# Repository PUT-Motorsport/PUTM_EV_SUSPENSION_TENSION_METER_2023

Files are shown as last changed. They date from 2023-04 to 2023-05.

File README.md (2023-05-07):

# Suspension Tension Meter

This circuit is supposed to measure uniaxial forces acting on the push-rods and send collected data over the CAN bus.

<p align="center">
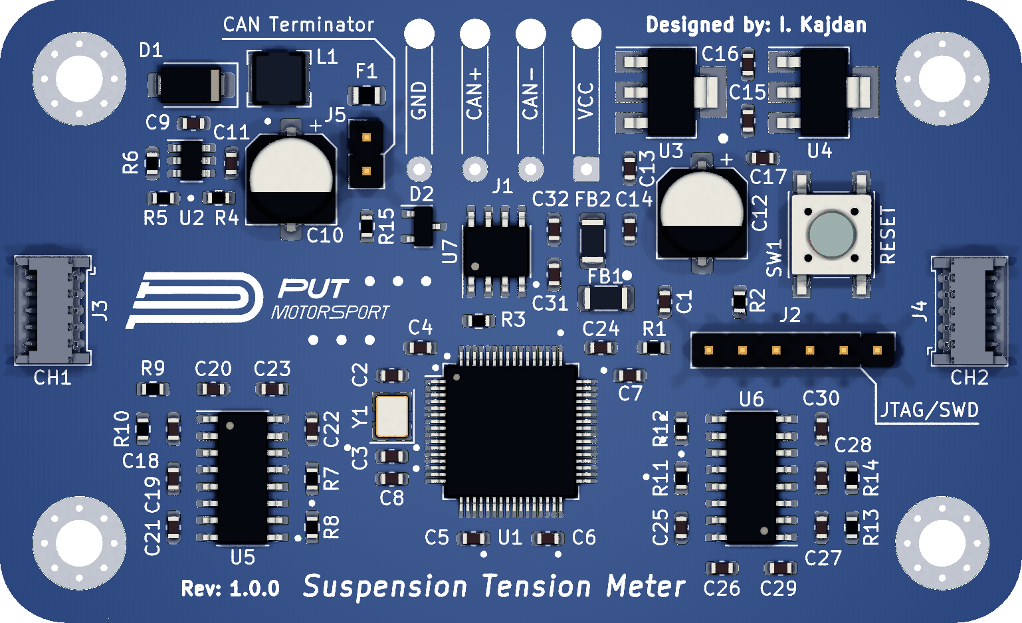
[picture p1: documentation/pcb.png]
  
</p>

## Build

1. Clone the repository:
    ```
    git clone --recurse-submodules 'https://github.com/PUT-Motorsport/PUTM_EV_SUSPENSION_TENSION_METER_2023.git'
    ```
1. Import the project into the CubeIDE.
1. Temporarily rename `main.cpp` to `main.c`.
1. Run the Device Configuration Tool to update the code.
1. Rename `main.c` back to `main.cpp`.

## Firmware

The [Adafruit library](https://github.com/adafruit/Adafruit_NAU7802) and [this project](https://github.com/alex7709/ECE4180F19_CAN_Project) have been used as a reference for writing the driver for the NAU7802.

## Hardware

- [STM32L4P5RET6](https://www.st.com/resource/en/datasheet/stm32l4p5ae.pdf)
- [NAU7802 24-bit ADC](https://www.nuvoton.com/resource-files/NAU7802%20Data%20Sheet%20V1.7.pdf)
- [EMS20 Shear-web Load Cell](https://www.memidos.com/wp-content/uploads/2022/09/EMS20_en.pdf)

## License

    Copyright 2022 Ignacy Kajdan
    
    Licensed under the Apache License, Version 2.0 (the "License");
    you may not use this file except in compliance with the License.
    You may obtain a copy of the License at
    
      https://www.apache.org/licenses/LICENSE-2.0
    
    Unless required by applicable law or agreed to in writing, software
    distributed under the License is distributed on an "AS IS" BASIS,
    WITHOUT WARRANTIES OR CONDITIONS OF ANY KIND, either express or implied.
    See the License for the specific language governing permissions and
    limitations under the License.

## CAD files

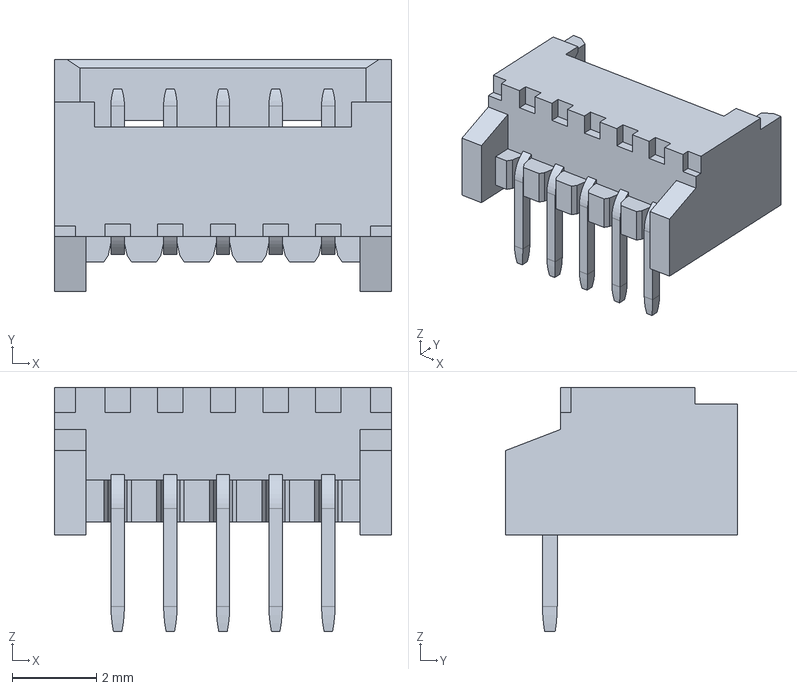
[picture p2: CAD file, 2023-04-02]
hardware/models/Molex_PicoBlade_53048-0510.step
8.00 x 5.50 x 5.80 mm

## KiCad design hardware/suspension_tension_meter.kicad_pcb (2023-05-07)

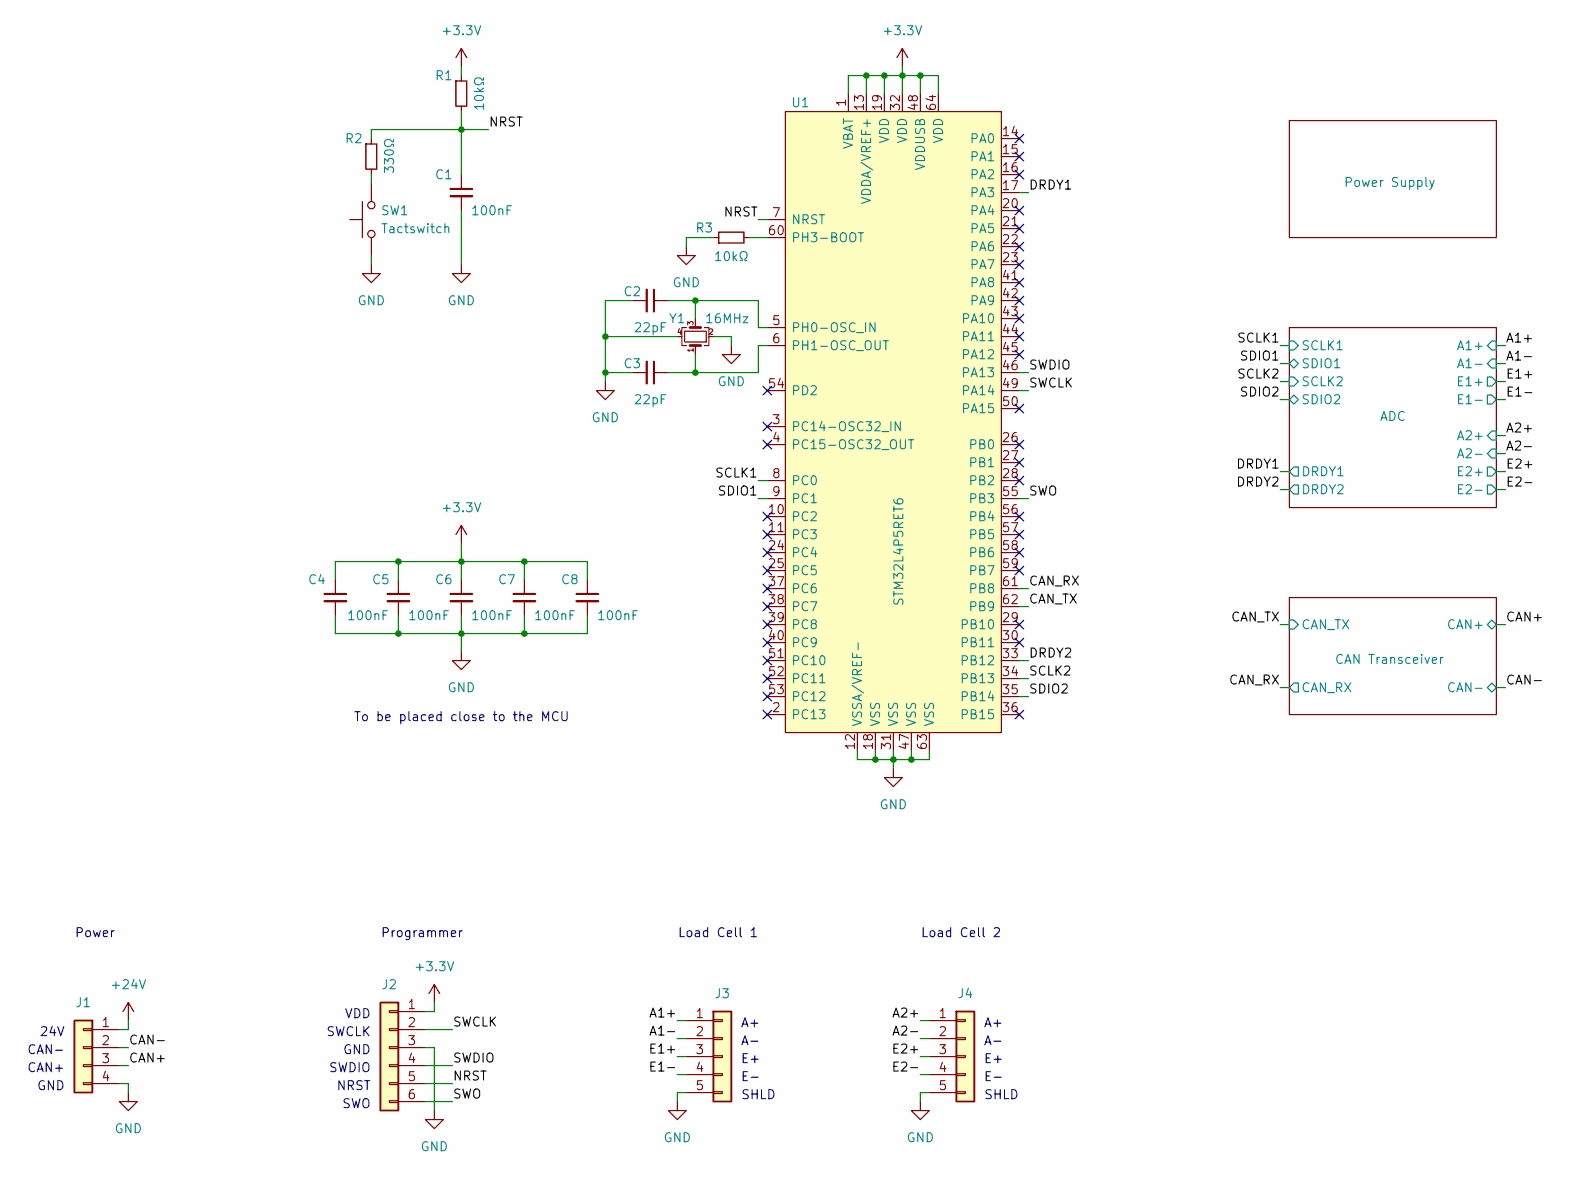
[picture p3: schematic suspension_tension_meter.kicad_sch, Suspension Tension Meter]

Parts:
C1, C4, C5, C6, C7, C8: 100nF; C_0603_1608Metric
C2, C3: 22pF; C_0603_1608Metric
J1: Conn_01x04; SolderWire-0.25sqmm_1x04_P4.2mm_D0.65mm_OD1.7mm_Relief
J2: Conn_01x06; PinHeader_1x06_P2.54mm_Vertical
J3, J4: Conn_01x04; Molex_PicoBlade_53048-0510_1x05_P1.25mm_Horizontal
R1, R3: 10kΩ; R_0603_1608Metric
R2: 330Ω; R_0603_1608Metric
SW1: Tactswitch; SW_SPST_PTS645
U1: STM32L4P5RET6; LQFP-64_10x10mm_P0.5mm
Y1: 16MHz; Crystal_SMD_3225-4Pin_3.2x2.5mm

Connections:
+3.3V: C4.1, C5.1, C6.1, C7.1, C8.1, J2.1, J3.3, J4.3, R1.1, U1.1 (VBAT), U1.13 (VDDA/VREF+), U1.19 (VDD), U1.32 (VDD), U1.48 (VDDUSB), U1.64 (VDD); also elsewhere on the board
+24V: J1.1; also elsewhere on the board
/A1+: J3.1; also elsewhere on the board
/A1-: J3.2; also elsewhere on the board
/A2+: J4.1; also elsewhere on the board
/A2-: J4.2; also elsewhere on the board
/CAN+: J1.3; also elsewhere on the board
/CAN-: J1.2; also elsewhere on the board
/CAN_RX: U1.61 (PB8); also elsewhere on the board
/CAN_TX: U1.62 (PB9); also elsewhere on the board
/DRDY1: U1.17 (PA3); also elsewhere on the board
/DRDY2: U1.33 (PB12); also elsewhere on the board
/NRST: C1.1, J2.5, R1.2, R2.1, U1.7 (NRST)
/SCLK1: U1.8 (PC0); also elsewhere on the board
/SCLK2: U1.34 (PB13); also elsewhere on the board
/SDIO1: U1.9 (PC1); also elsewhere on the board
/SDIO2: U1.35 (PB14); also elsewhere on the board
/SWCLK: J2.2, U1.49 (PA14)
/SWDIO: J2.4, U1.46 (PA13)
/SWO: J2.6, U1.55 (PB3)
GND: C1.2, C2.2, C3.2, C4.2, C5.2, C6.2, C7.2, C8.2, J1.4, J2.3, J3.4, J3.5, J4.4, J4.5, R3.1, SW1.1, U1.12 (VSSA/VREF-), U1.18 (VSS), U1.31 (VSS), U1.47 (VSS), U1.63 (VSS), Y1.2, Y1.4; also elsewhere on the board
unnamed: R2.2, SW1.2
unnamed: C2.1, U1.5 (PH0-OSC_IN), Y1.3
unnamed: C3.1, U1.6 (PH1-OSC_OUT), Y1.1
unnamed: R3.2, U1.60 (PH3-BOOT)

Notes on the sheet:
GND
Power
SHLD
To be placed close to the MCU
Load Cell 2
SWCLK
CAN+
NRST
SWO
SHLD
Load Cell 1
CAN-
VDD
Programmer
SWDIO
24V

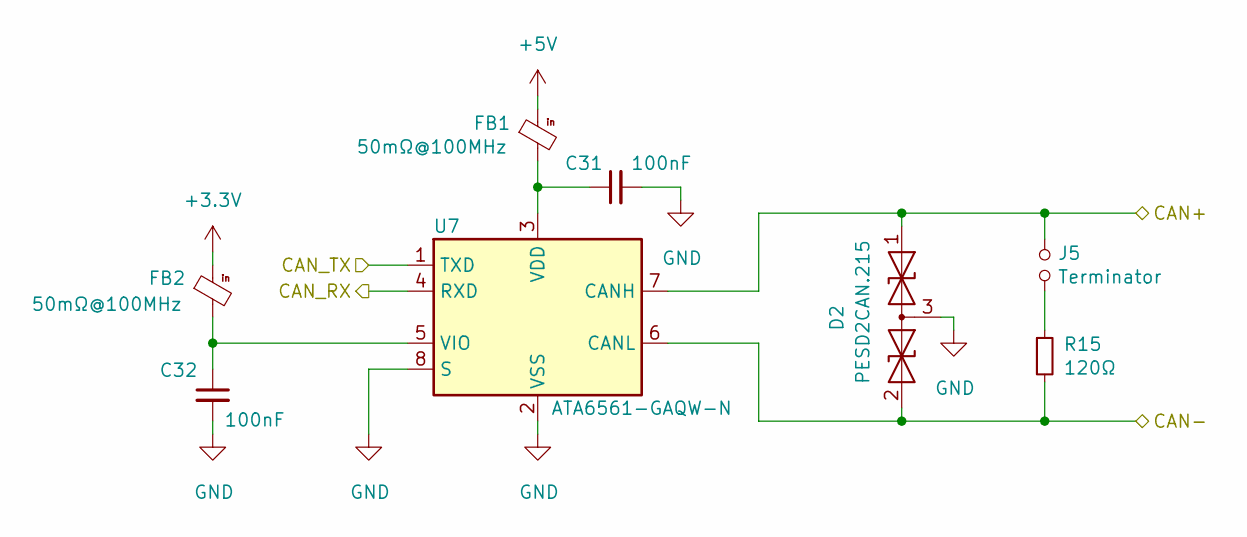
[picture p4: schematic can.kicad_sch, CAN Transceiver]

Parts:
C31, C32: 100nF; C_0603_1608Metric
D2: PESD2CAN.215; SOT-23
FB1, FB2: 50mΩ@100MHz; L_1206_3216Metric
J5: Terminator; PinHeader_1x02_P2.54mm_Vertical
R15: 120Ω; R_0603_1608Metric
U7: ATA6561-GAQW-N; SOIC-8_3.9x4.9mm_P1.27mm

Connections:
+3.3V: FB2.1; also elsewhere on the board
+5V: FB1.1; also elsewhere on the board
/CAN+: D2.1 (A1), J5.1, U7.7 (CANH); also elsewhere on the board
/CAN-: D2.2 (A2), R15.2, U7.6 (CANL); also elsewhere on the board
/CAN_RX: U7.4 (RXD); also elsewhere on the board
/CAN_TX: U7.1 (TXD); also elsewhere on the board
GND: C31.2, C32.2, D2.3 (common), U7.2 (VSS), U7.8 (S); also elsewhere on the board
unnamed: J5.2, R15.1
unnamed: C31.1, FB1.2, U7.3 (VDD)
unnamed: C32.1, FB2.2, U7.5 (VIO)

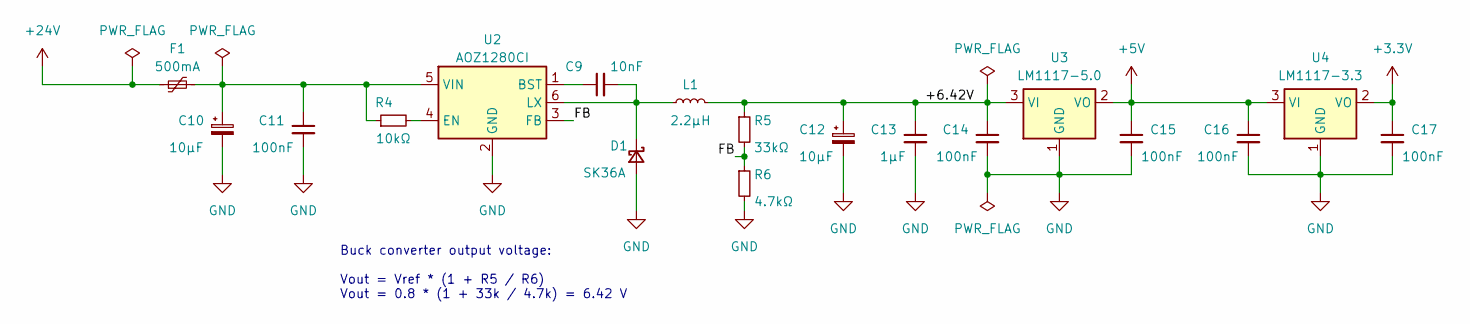
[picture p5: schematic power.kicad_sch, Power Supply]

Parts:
C9: 10nF; C_0603_1608Metric
C10, C12: 10μF; CP_Elec_6.3x5.4
C11, C14, C15, C16, C17: 100nF; C_0603_1608Metric
C13: 1μF; C_0603_1608Metric
D1: SK36A; D_SMA
F1: 500mA; Fuse_0805_2012Metric
L1: 2.2μH; L_Bourns-SRN4018
R4: 10kΩ; R_0603_1608Metric
R5: 33kΩ; R_0603_1608Metric
R6: 4.7kΩ; R_0603_1608Metric
U2: AOZ1280CI; SOT-23-6
U3: LM1117-5.0; SOT-223-3_TabPin2
U4: LM1117-3.3; SOT-223-3_TabPin2

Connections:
+3.3V: C17.1, U4.2 (VO); also elsewhere on the board
+5V: C15.1, C16.1, U3.2 (VO), U4.3 (VI); also elsewhere on the board
+24V: F1.1; also elsewhere on the board
/Power Supply/+6.42V: C12.1, C13.1, C14.1, L1.2, R5.1, U3.3 (VI)
/Power Supply/FB: R5.2, R6.1, U2.3 (FB)
GND: C10.2, C11.2, C12.2, C13.2, C14.2, C15.2, C16.2, C17.2, D1.2 (A), R6.2, U2.2 (GND), U3.1 (GND), U4.1 (GND); also elsewhere on the board
unnamed: C10.1, C11.1, F1.2, R4.1, U2.5 (VIN)
unnamed: C9.2, D1.1 (K), L1.1, U2.6 (LX)
unnamed: C9.1, U2.1 (BST)
unnamed: R4.2, U2.4 (EN)

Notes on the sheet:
Buck converter output voltage: Vout = Vref * (1 + R5 / R6) Vout = 0.8 * (1 + 33k / 4.7k) = 6.42 V

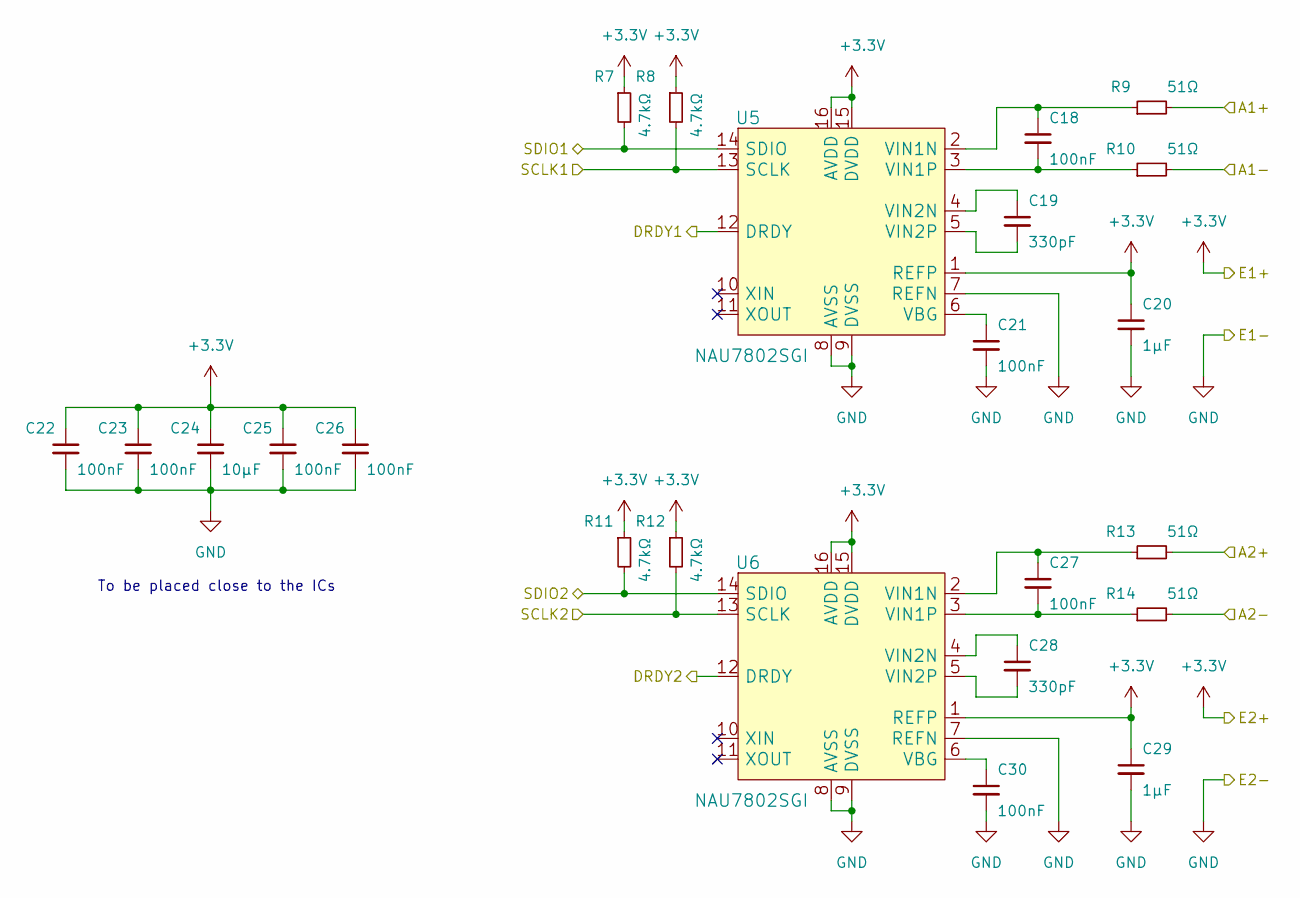
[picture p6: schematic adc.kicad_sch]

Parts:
C18, C21, C22, C23, C25, C26, C27, C30: 100nF; C_0603_1608Metric
C19, C28: 330pF; C_0603_1608Metric
C20, C29: 1μF; C_0603_1608Metric
C24: 10μF; C_0603_1608Metric
R7, R8, R11, R12: 4.7kΩ; R_0603_1608Metric
R9, R10, R13, R14: 51Ω; R_0603_1608Metric
U5, U6: NAU7802SGI; SOIC-16_3.9x9.9mm_P1.27mm

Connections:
+3.3V: C20.1, C22.1, C23.1, C24.1, C25.1, C26.1, C29.1, R7.1, R8.1, R11.1, R12.1, U5.1 (REFP), U5.15 (DVDD), U5.16 (AVDD), U6.1 (REFP), U6.15 (DVDD), U6.16 (AVDD); also elsewhere on the board
/A1+: R9.2; also elsewhere on the board
/A1-: R10.2; also elsewhere on the board
/A2+: R13.2; also elsewhere on the board
/A2-: R14.2; also elsewhere on the board
/DRDY1: U5.12 (DRDY); also elsewhere on the board
/DRDY2: U6.12 (DRDY); also elsewhere on the board
/SCLK1: R8.2, U5.13 (SCLK); also elsewhere on the board
/SCLK2: R12.2, U6.13 (SCLK); also elsewhere on the board
/SDIO1: R7.2, U5.14 (SDIO); also elsewhere on the board
/SDIO2: R11.2, U6.14 (SDIO); also elsewhere on the board
GND: C20.2, C21.2, C22.2, C23.2, C24.2, C25.2, C26.2, C29.2, C30.2, U5.7 (REFN), U5.8 (AVSS), U5.9 (DVSS), U6.7 (REFN), U6.8 (AVSS), U6.9 (DVSS); also elsewhere on the board
unnamed: C21.1, U5.6 (VBG)
unnamed: C18.1, R9.1, U5.2 (VIN1N)
unnamed: C18.2, R10.1, U5.3 (VIN1P)
unnamed: C19.1, U5.4 (VIN2N)
unnamed: C19.2, U5.5 (VIN2P)
unnamed: C30.1, U6.6 (VBG)
unnamed: C27.1, R13.1, U6.2 (VIN1N)
unnamed: C27.2, R14.1, U6.3 (VIN1P)
unnamed: C28.1, U6.4 (VIN2N)
unnamed: C28.2, U6.5 (VIN2P)

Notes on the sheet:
To be placed close to the ICs

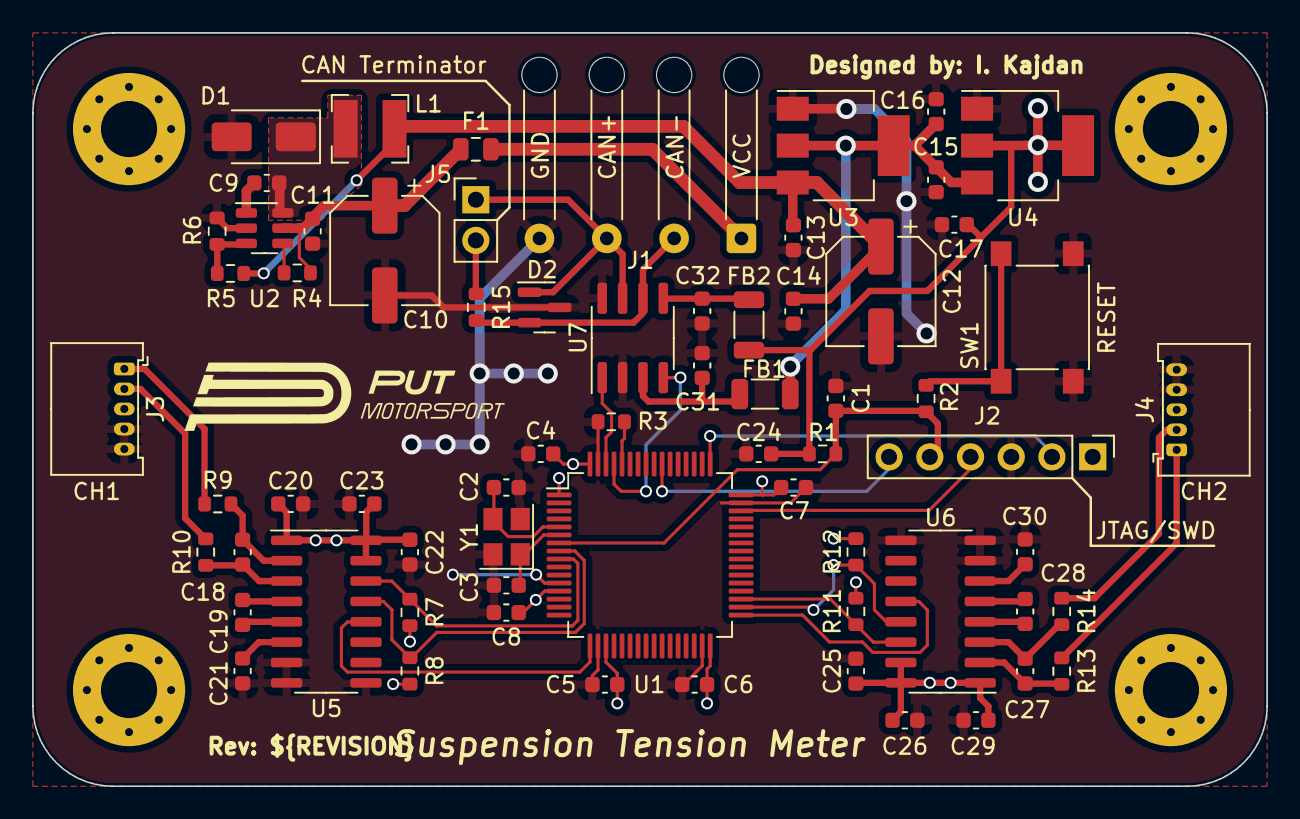
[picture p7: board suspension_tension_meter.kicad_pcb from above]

Board: 2 copper layers, 77.0 x 47.0 mm, 67 parts (0 on the bottom side), 45 nets.

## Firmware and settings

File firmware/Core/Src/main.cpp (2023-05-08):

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
/* Includes ------------------------------------------------------------------*/
#include "main.h"
#include "can.h"
#include "i2c.h"
#include "gpio.h"

/* USER CODE BEGIN Includes */
#include "nau7802.hpp"
#include "PM08-CANBUS-SUSMETER.hpp" // TODO: Upstream this
#include "PUTM_EV_CAN_LIBRARY/lib/can.hpp"
/* USER CODE END Includes */


/* USER CODE BEGIN PV */
uint8_t result_ch1[8];
uint8_t result_ch2[8];
/* USER CODE END PV */

void SystemClock_Config(void);
/**
 * @brief  The application entry point.
 * @retval int
 */
int main(void)
{
	/* MCU Configuration--------------------------------------------------------*/

	/* Reset of all peripherals, Initializes the Flash interface and the Systick. */
	HAL_Init();

	/* Configure the system clock */
	SystemClock_Config();

	/* Initialize all configured peripherals */
	MX_GPIO_Init();
	MX_CAN1_Init();
	MX_I2C2_Init();
	MX_I2C3_Init();
	/* USER CODE BEGIN 2 */
	NAU7802_Init(hi2c3); // CH1
	NAU7802_Switch_Channel(hi2c3, NAU7802_CHANNEL_1);
	NAU7802_Init(hi2c2); // CH2
	NAU7802_Switch_Channel(hi2c2, NAU7802_CHANNEL_1);

	PUTM_CAN::Can can(&hcan1, &PUTM_CAN::filter::null_filter);
	/* USER CODE END 2 */

	/* Infinite loop */
	/* USER CODE BEGIN WHILE */
	while(1)
	{
		/* USER CODE END WHILE */

		/* USER CODE BEGIN 3 */
		NAU7802_Read(hi2c3, result_ch1);
		NAU7802_Read(hi2c2, result_ch2);

		PUTM_CAN::Susmeter_data data {
			.tension_left = result_ch1[8],
			.tension_right = result_ch2[8]
		};

		can.send(data);

		HAL_Delay(100); // TODO: Rewrite using interrupts
	}
	/* USER CODE END 3 */
}

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


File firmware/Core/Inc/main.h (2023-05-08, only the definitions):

#define SCLK1_Pin GPIO_PIN_0
#define SCLK1_GPIO_Port GPIOC
#define SDIO1_Pin GPIO_PIN_1
#define SDIO1_GPIO_Port GPIOC
#define DRDY1_Pin GPIO_PIN_3
#define DRDY1_GPIO_Port GPIOA
#define DRDY2_Pin GPIO_PIN_12
#define DRDY2_GPIO_Port GPIOB
#define SCLK2_Pin GPIO_PIN_13
#define SCLK2_GPIO_Port GPIOB
#define SDIO2_Pin GPIO_PIN_14
#define SDIO2_GPIO_Port GPIOB
#define SWDIO_Pin GPIO_PIN_13
#define SWDIO_GPIO_Port GPIOA
#define SWCLK_Pin GPIO_PIN_14
#define SWCLK_GPIO_Port GPIOA
#define SWO_Pin GPIO_PIN_3
#define SWO_GPIO_Port GPIOB
#define CAN_RX_Pin GPIO_PIN_8
#define CAN_RX_GPIO_Port GPIOB
#define CAN_TX_Pin GPIO_PIN_9
#define CAN_TX_GPIO_Port GPIOB

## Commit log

2022-11-21 Improve the CAN transceiver circuit
    [can_transceiver.kicad_sch, power_delivery.kicad_sch, suspension_tension_meter.kicad_sch]
2022-11-21 Add a low-pass filter to the analog circuit supply
    [power_delivery.kicad_sch, suspension_tension_meter.kicad_sch]
2022-11-29 Improve power delivery sheet:
    - Move power connector to the main sheet
    - Use PTC fuse
    [power_delivery.kicad_sch, suspension_tension_meter.kicad_sch]
2022-11-30 Refactor the main sheet
    - Replace screw connectors with a goldpin header
    - Add reset button
    - Add SWD debugger header
    [can_transceiver.kicad_sch, power_delivery.kicad_sch, suspension_tension_meter.kicad_sch]
2022-12-04 Add ADC circuit
    [adc.kicad_sch, can_transceiver.kicad_sch, power_delivery.kicad_sch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]
2022-12-04 Connect each ADC to a separate I2C bus
    [adc.kicad_sch, suspension_tension_meter.kicad_sch]
2022-12-05 Assign footprints to symbols
    [adc.kicad_sch, can.kicad_sch, power.kicad_sch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]
2022-12-06 Use more efficient buck converter
    [adc.kicad_sch, can.kicad_sch, power.kicad_sch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]
2022-12-10 Arrange footprints
    [adc.kicad_sch, can.kicad_sch, power.kicad_sch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]
2022-12-11 Make the PCB more compact
    [suspension_tension_meter.kicad_pcb]
2022-12-11 Apply PUTM branding
    [adc.kicad_sch, can.kicad_sch, power.kicad_sch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]
2022-12-18 Miscellaneous changes
    - Use THT connectors
    - Adjust ADC circuit according to the datasheet
    [adc.kicad_sch, can.kicad_sch, power.kicad_sch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]
2022-12-19 Route PCB tracks
    [adc.kicad_sch, can.kicad_sch, power.kicad_sch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]
2022-12-19 Add PCB render to the README
2022-12-22 Move input capacitor closer to the converter IC
    [adc.kicad_sch, can.kicad_sch, power.kicad_sch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]
2022-12-22 Improve routing around the buck converter
    [power.kicad_sch, suspension_tension_meter.kicad_pcb, suspension_tension_meter.kicad_sch]
2022-12-28 Release v1.0.0
    [adc.kicad_sch, can.kicad_sch, power.kicad_sch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]
2023-03-13 Port the project to KiCad 7
    [adc.kicad_sch, can.kicad_sch, power.kicad_sch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]
2023-04-01 Implement NAU7802 driver
2023-04-02 Add a 3D model for the connectors
    [Molex_PicoBlade_53048-0510.step, suspension_tension_meter.kicad_pcb]
2023-04-02 Update the PCB render
2023-05-07 Apply KiCad template to the project
    [adc.kicad_sch, can.kicad_sch, power.kicad_sch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]
2024-04-16 Added new, debugged power supply, but the old one is still there, just in case
    [adc.kicad_sch, can.kicad_sch, power.kicad_sch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]
2024-05-14 finalna wersja zasilania, zatwierdzona
    [power.kicad_sch]

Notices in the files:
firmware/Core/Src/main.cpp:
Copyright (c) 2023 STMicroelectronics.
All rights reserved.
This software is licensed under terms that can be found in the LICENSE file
